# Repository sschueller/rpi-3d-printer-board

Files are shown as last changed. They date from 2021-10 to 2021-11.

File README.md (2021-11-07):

# Raspberry Pi 3D Printer Aux Board

This simple RPI board fits ontop of an RPI3+ and can supply it with power without requiring any external extras. It provides a few general features used in 3d printing and simplifies the wiring required. To control the fans, LEDs, relays etc. the https://plugins.octoprint.org/plugins/enclosure/ is recommended 

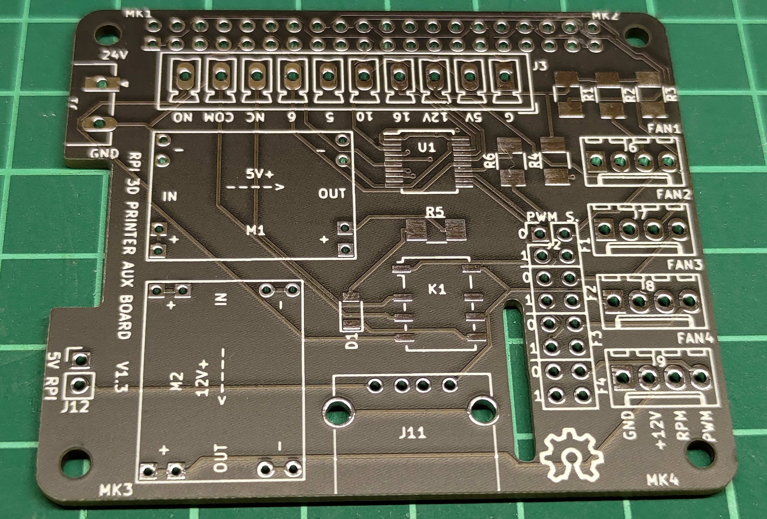
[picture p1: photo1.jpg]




## Features
- 12V - 28V In
- 12V Out
- 5V Out
- 5V (Max 3A) power directly to Raspberry Pi
- Built in relay (NC and NO connetions)
- 4 x 12V fan connections with PWM and RPM
- Per fan selectable PWM (PWM0 or PWM1)
- 4 x Exposed GPIO (5,6,10,16) level shifted to 5V (Output Only) 
- LED indicator for relay
- USB Power Out port

## BOM

| Symbol  | Part  | Notes |
|---|---|---|
| M1A  | LM2596 | tuned to 5.1V (use 4 x 2.54m 2-pin header to connect)  |
| M2A  | LM2596 | tuned to 12V (use 4 x 2.54m 2-pin header to connect)  |
| U1  | SN74HCT245 | 20-SSOP (0,209", 5,30mm Width) |
| K1  | G6K-2F-Y (5V) | |
| D1  | 1206 SMD LED | |
| R1  | 1206 SMD 2.2k | |
| R2  | 1206 SMD 2.2k | |
| R3  | 1206 SMD 2.2k | |
| R4  | 1206 SMD 2.2k | |
| R5  | 1206 SMD 150 Ohm | |
| R6  | 1206 SMD 0 Ohm (bridge) | |
| P1  | RPI 2.54m 2x20-pin female header | |
| J1  | 2-poin Phoenix Contact screw terminal 5.08mm | |
| J2  | 2.54mm 2x8-pin header | |
| J3  | Phoenix Contact 10x3.81mm Vertical | |
| J6  | 2510 2.54mm KF2510 3+1P | |
| J7  | 2510 2.54mm KF2510 3+1P | |
| J8  | 2510 2.54mm KF2510 3+1P | |
| J9  | 2510 2.54mm KF2510 3+1P | |
| J11 | USB Type A Female 4Pin Socket Connector For PCB - through hole | |
| J12 | 2.54mm 2-pin header | |

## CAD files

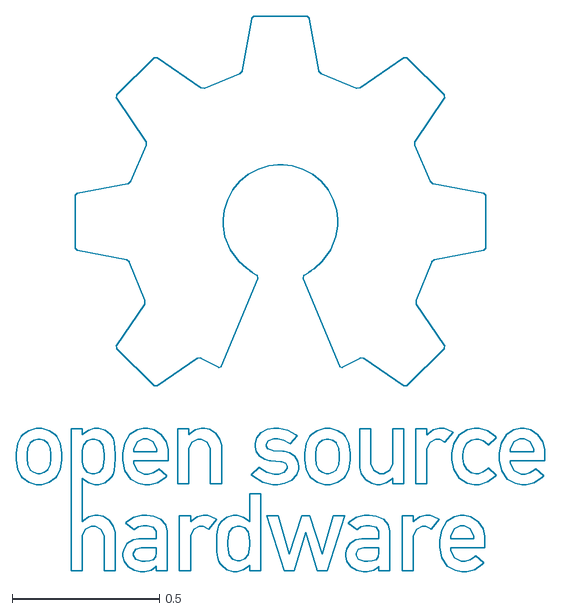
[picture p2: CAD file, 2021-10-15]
Open-source-hardware-logo.dxf
1.79 x 1.89

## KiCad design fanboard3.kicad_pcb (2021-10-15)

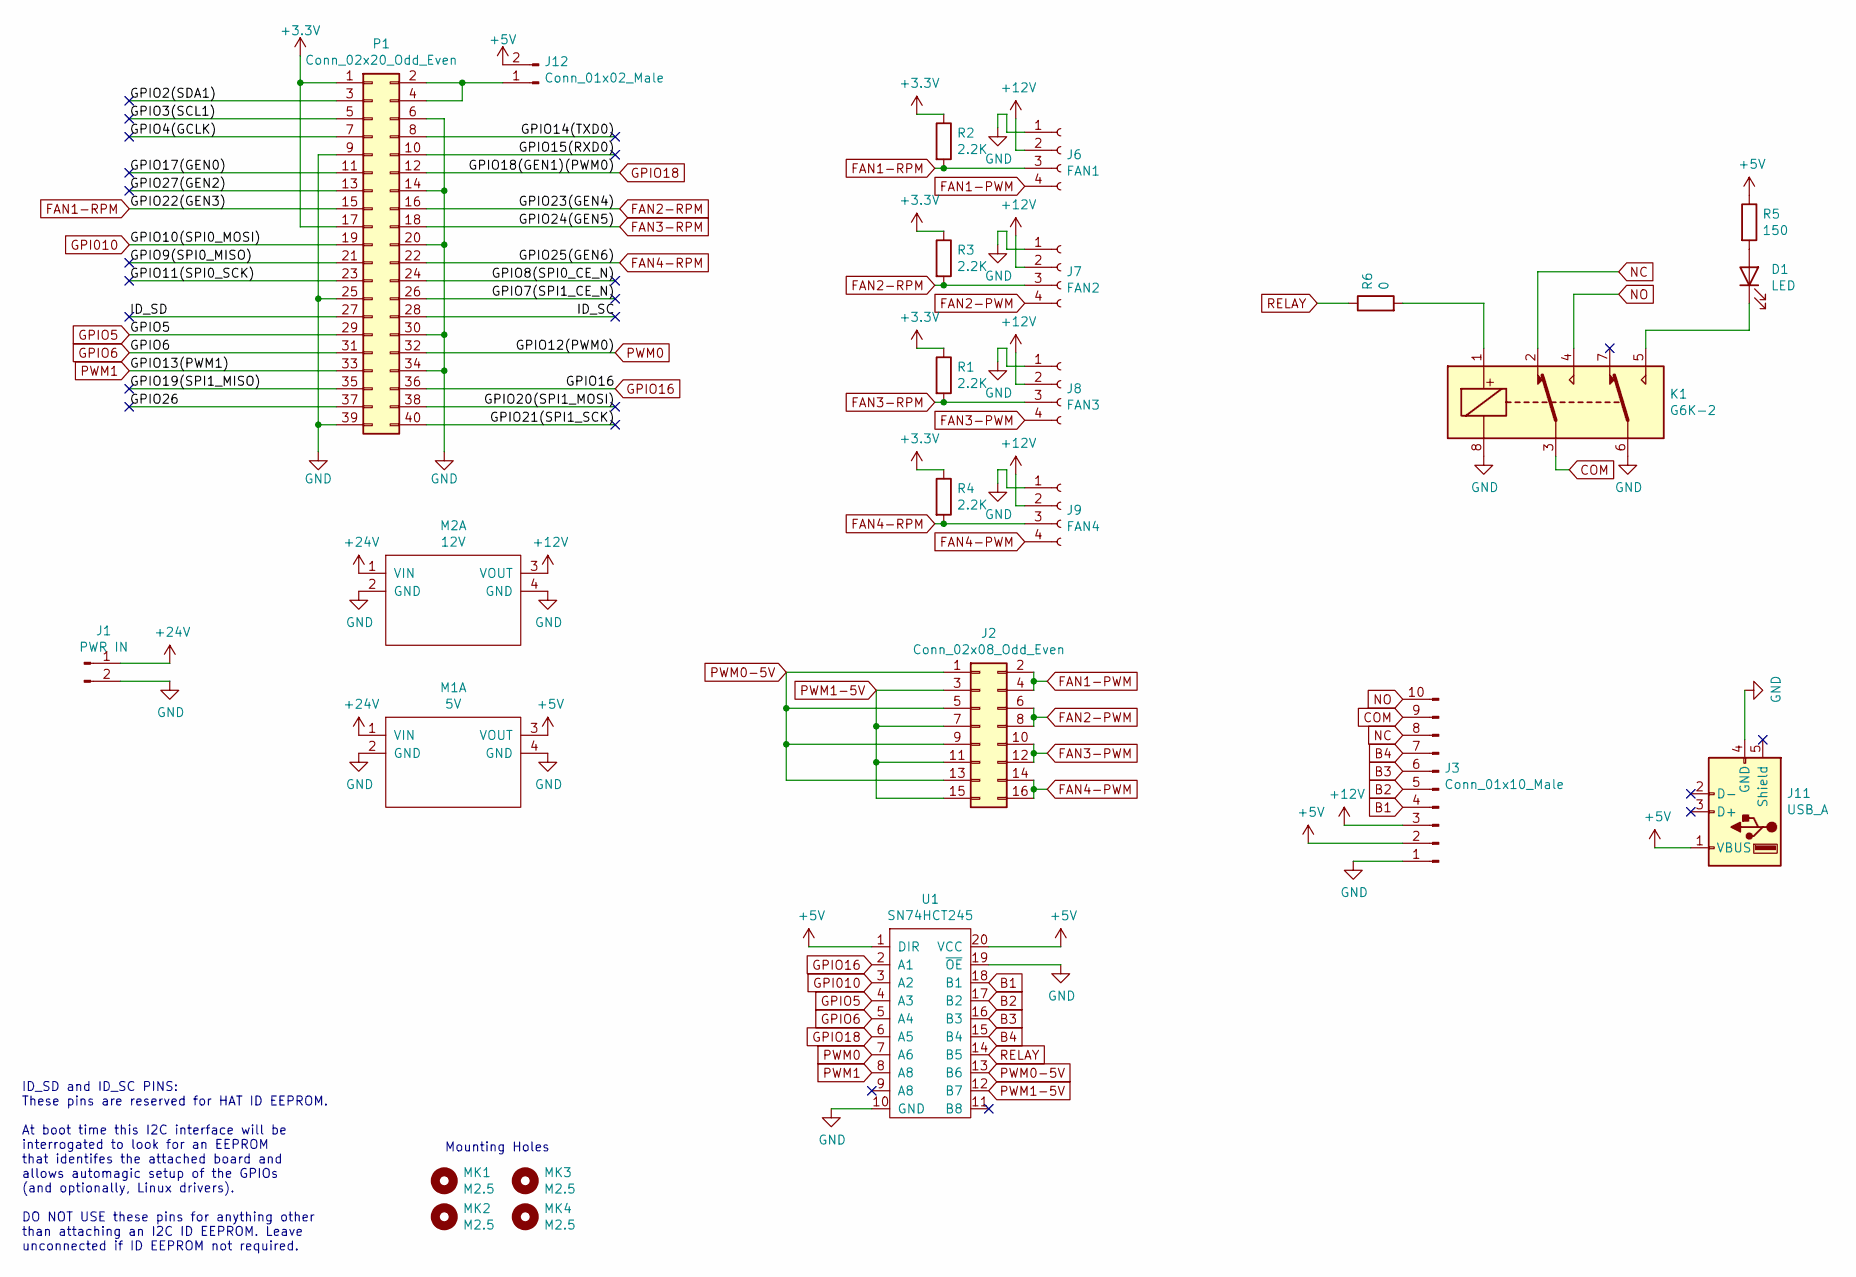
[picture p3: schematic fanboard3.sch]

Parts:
D1: LED; D_1206
J1: PWR IN; PhoenixContact_MC-G_02x5.08mm_Angled
J2: Conn_02x08_Odd_Even; Pin_Header_Straight_2x08_Pitch2.54mm
J3: Conn_01x10_Male; PhoenixContact_MCV-G_10x3.81mm_Vertical
J6: FAN1; Molex_KK-6410-04_04x2.54mm_Straight
J7: FAN2; Molex_KK-6410-04_04x2.54mm_Straight
J8: FAN3; Molex_KK-6410-04_04x2.54mm_Straight
J9: FAN4; Molex_KK-6410-04_04x2.54mm_Straight
J11: USB_A
J12: Conn_01x02_Male; Pin_Header_Straight_1x02_Pitch2.54mm
K1: G6K-2; Relay_DPDT_Omron_G6K-2F-Y
M1: 5V; buck-converter-module
M2: 12V; buck-converter-module
MK1, MK2, MK3, MK4: M2.5; MountingHole_2.7mm_M2.5
P1: Conn_02x20_Odd_Even; PinSocket_2x20_P2.54mm_Vertical
R1, R2, R3, R4: 2.2K; R_1210_HandSoldering
R5: 150; R_1210_HandSoldering
R6: 0; R_1210_HandSoldering
U1: SN74HCT245; SSOP-20_5.3x7.2mm_Pitch0.65mm

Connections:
+3V3: P1.1, P1.17, R1.1, R2.1, R3.1, R4.1
+5V: J3.2, J11.1 (VBUS), J12.2, M1.3 (VOUT), R5.1, U1.1 (DIR), U1.20 (VCC)
+12V: J3.3, J6.2, J7.2, J8.2, J9.2, M2.3 (VOUT)
+24V: J1.1, M1.1 (VIN), M2.1 (VIN)
/GPIO2(SDA1): P1.3
/GPIO3(SCL1): P1.5
/GPIO4(GCLK): P1.7
/GPIO7(SPI1_CE_N): P1.26
/GPIO8(SPI0_CE_N): P1.24
/GPIO9(SPI0_MISO): P1.21
/GPIO11(SPI0_SCK): P1.23
/GPIO14(TXD0): P1.8
/GPIO15(RXD0): P1.10
/GPIO17(GEN0): P1.11
/GPIO19(SPI1_MISO): P1.35
/GPIO20(SPI1_MOSI): P1.38
/GPIO21(SPI1_SCK): P1.40
/GPIO26: P1.37
/GPIO27(GEN2): P1.13
/ID_SC: P1.28
/ID_SD: P1.27
B1: J3.4, U1.18 (B1)
B2: J3.5, U1.17 (B2)
B3: J3.6, U1.16 (B3)
B4: J3.7, U1.15 (B4)
COM: J3.9, K1.3
FAN1-PWM: J2.2, J2.4, J6.4
FAN1-RPM: J6.3, P1.15, R2.2
FAN2-PWM: J2.6, J2.8, J7.4
FAN2-RPM: J7.3, P1.16, R3.2
FAN3-PWM: J2.10, J2.12, J8.4
FAN3-RPM: J8.3, P1.18, R1.2
FAN4-PWM: J2.14, J2.16, J9.4
FAN4-RPM: J9.3, P1.22, R4.2
GND: J1.2, J3.1, J6.1, J7.1, J8.1, J9.1, J11.4 (GND), K1.6, K1.8, M1.2 (GND), M1.4 (GND), M2.2 (GND), M2.4 (GND), P1.6, P1.9, P1.14, P1.20, P1.25, P1.30, P1.34, P1.39, U1.10 (GND), U1.19 (~OE)
GPI010: P1.19, U1.3 (A2)
GPIO5: P1.29, U1.4 (A3)
GPIO6: P1.31, U1.5 (A4)
GPIO16: P1.36, U1.2 (A1)
GPIO18: P1.12, U1.6 (A5)
NC: J3.8, K1.2
NO: J3.10, K1.4
unnamed: D1.1 (K), K1.5
unnamed: D1.2 (A), R5.2
unnamed: J12.1, P1.2, P1.4
unnamed: K1.1, R6.2
PWM0: P1.32, U1.7 (A6)
PWM0-5V: J2.1, J2.5, J2.9, J2.13, U1.13 (B6)
PWM1: P1.33, U1.8 (A8)
PWM1-5V: J2.3, J2.7, J2.11, J2.15, U1.12 (B7)
RELAY: R6.1, U1.14 (B5)

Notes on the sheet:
ID_SD and ID_SC PINS: These pins are reserved for HAT ID EEPROM. At boot time this I2C interface will be interrogated to look for an EEPROM that identifes the attached board and allows automagic setup of the GPIOs (and optionally, Linux drivers). DO NOT USE these pins for anything other than attach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
Mounting Holes

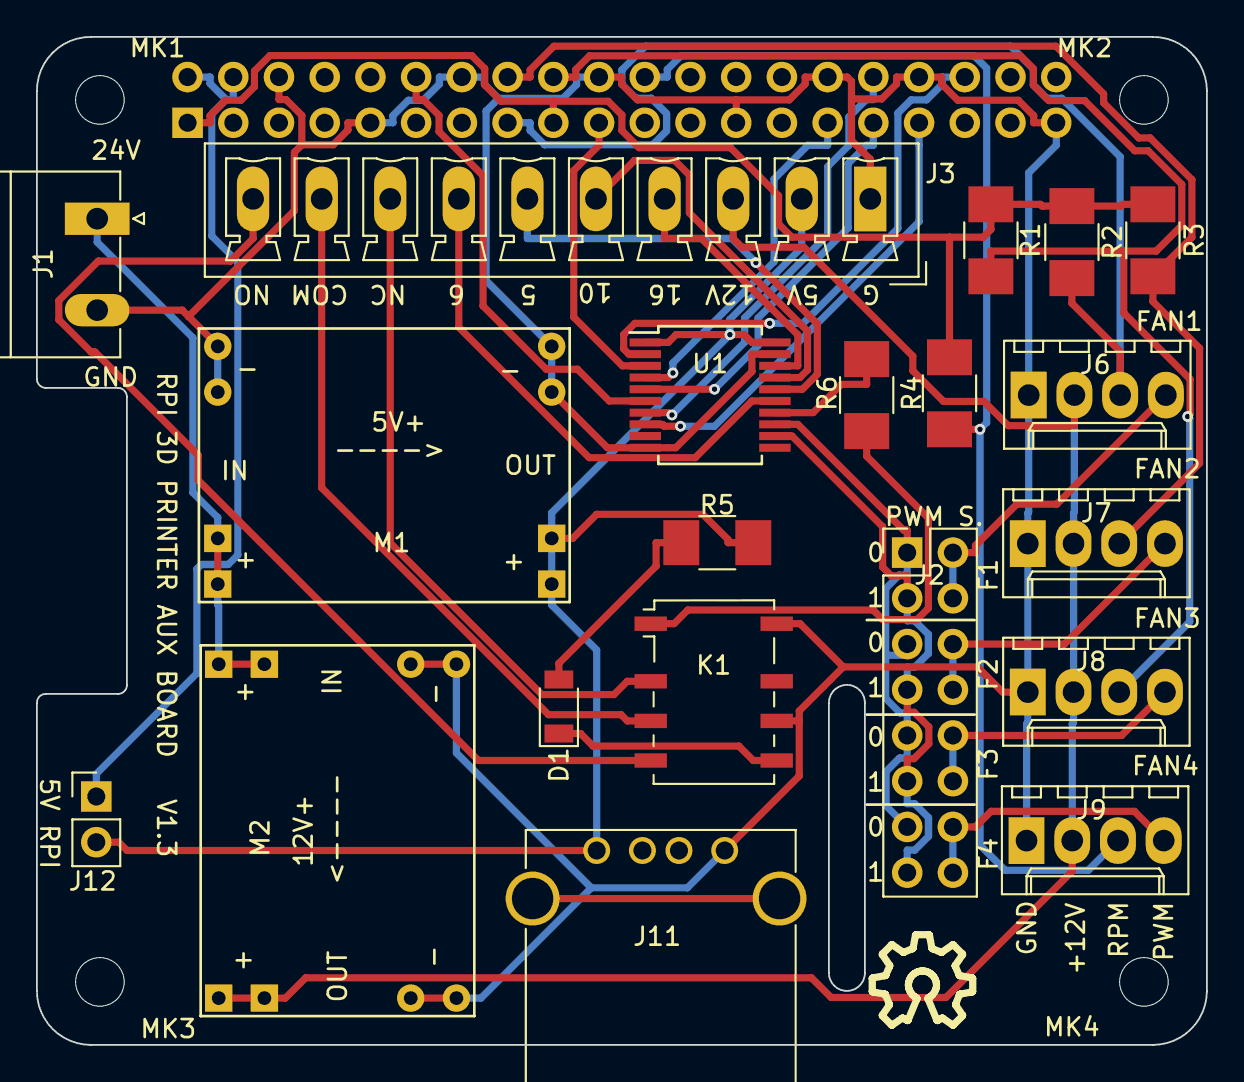
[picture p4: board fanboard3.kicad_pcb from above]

Board: 2 copper layers, 65.0 x 56.0 mm, 25 parts (1 on the bottom side), 34 nets.

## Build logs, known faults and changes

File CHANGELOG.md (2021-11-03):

## 1.0.1 (2021-10-17)

### Bug Fixes

* CI 7c0ebf3

# 1.0.0 (2021-10-17)

### Bug Fixes

* Added Title to Readme 6cb25be

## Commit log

2021-09-17 added Volt meter and changed layout
    [fanboard3.kicad_pcb, fanboard3.sch]
2021-11-07 BOM fixes
